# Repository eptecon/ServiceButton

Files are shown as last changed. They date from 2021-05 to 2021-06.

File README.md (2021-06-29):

ServiceButton: Connected Button for Notifications and Alarms
======

WiFi connected button that sends push notification data to an IoT platform. The notifications can be configured depending on use case.
Possible business cases are presented [here](/Docs).

### Hardware

ESP32 Microcontroller, simple push button, rechargeable battery.

### Firmware

The deevice connects with a server over WLAN. When button pressed, a notification message is composed from previously configured
data. The notification message is then sent in JSON format via TLS-secured MQTT protocol to the cloud service ([GlueLogics](https://github.com/eptecon/gluelogics)).

---

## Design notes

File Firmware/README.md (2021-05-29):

# GlueLogics Service Button

See the README.md file in the upper level directory for more information about this code.

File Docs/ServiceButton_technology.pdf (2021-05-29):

## Button – Use Case

Customer | Service Company

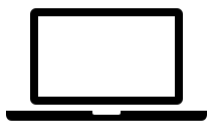
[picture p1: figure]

### Button on customer‘s side

### Service/Order Request in Service App

### Notifications/E-Mails to persons in charge and feedback to customer

Service App | E-Mail | Messenger

Button pressed by
customer

Action taken by
Service Company

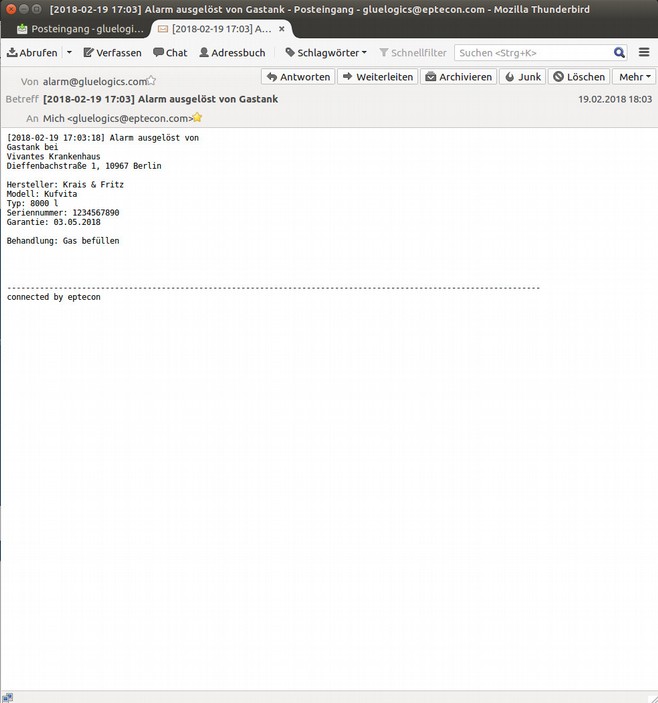
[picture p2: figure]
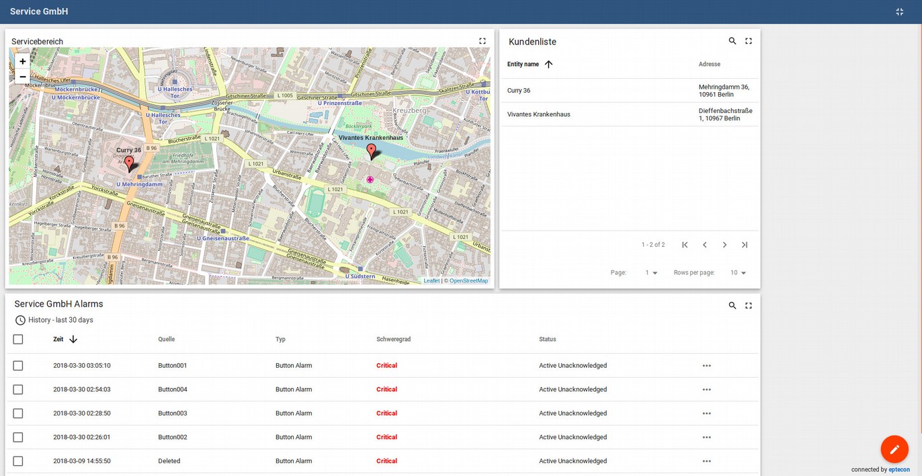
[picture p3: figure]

## Button – Business Process

### Button pressed by customer

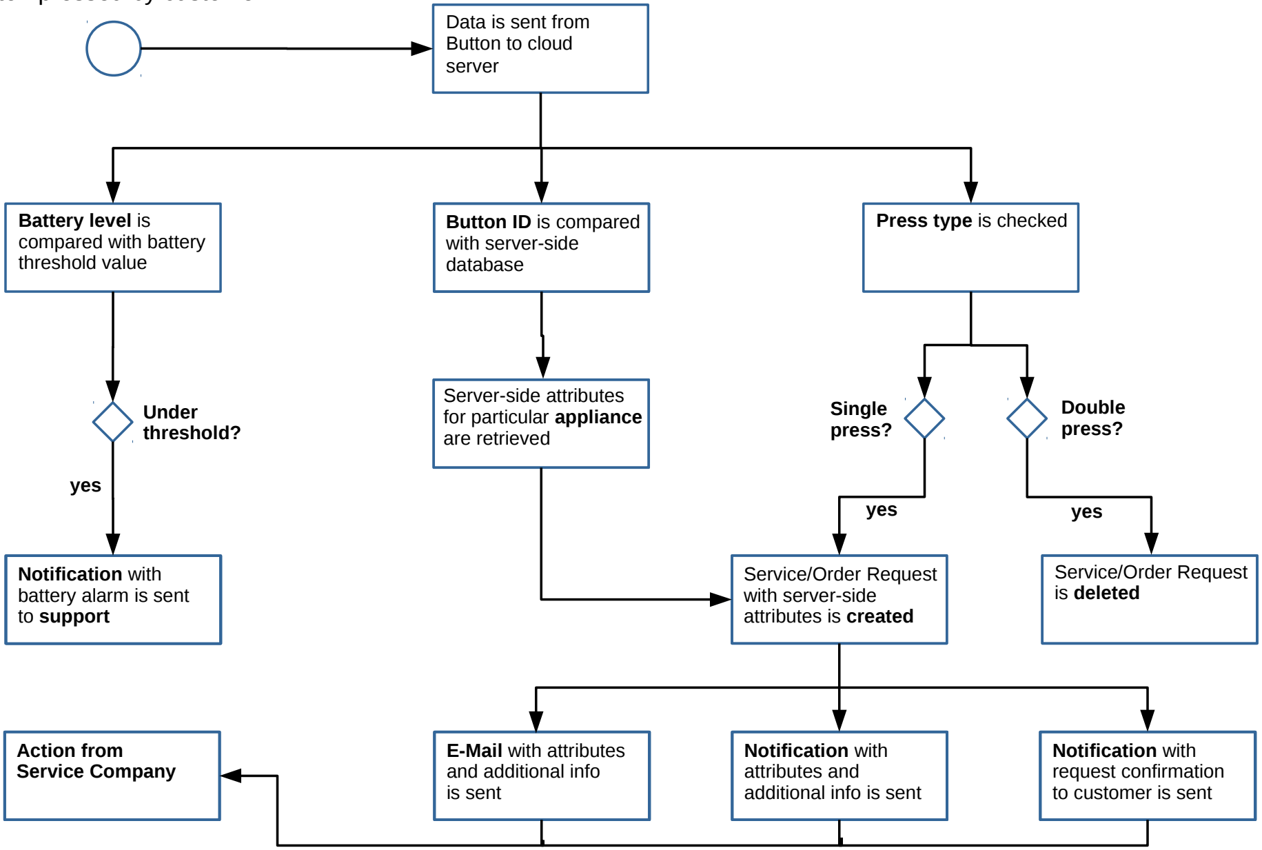
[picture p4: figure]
Data is sent from Button to cloud server; Button ID is compared with server-side database; Battery level is compared with battery threshold value; Press type is checked; Double press?; Single press?; Under threshold?; Service/Order Request with server-side attributes is created; Service/Order Request is deleted; Server-side attributes for particular appliance are retrieved; E-Mail with attributes and additional info is sent; Notification with request confirmation to customer is sent; Notification with attributes and additional info is sent; Notification with battery alarm is sent to support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

## Service/Order Request – Example Service App

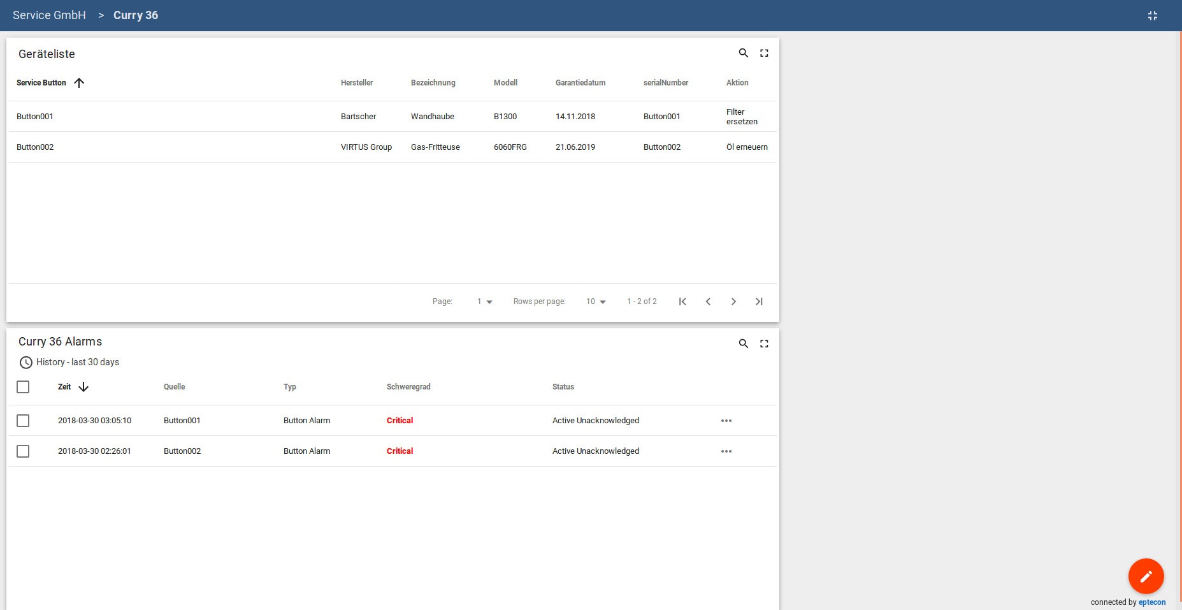
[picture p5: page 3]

## Service/Order Request – Example E-Mail

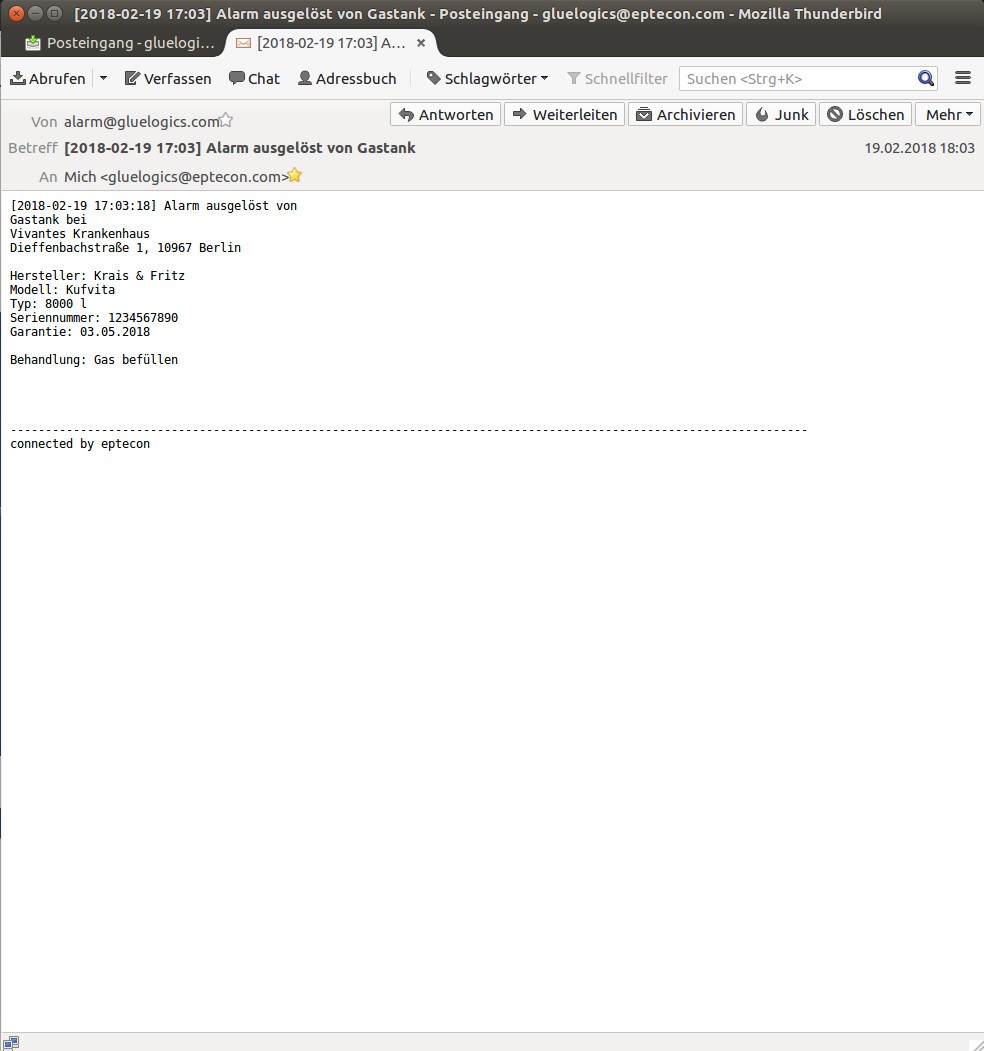
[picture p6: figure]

## Service/Order Request – Example Messenger

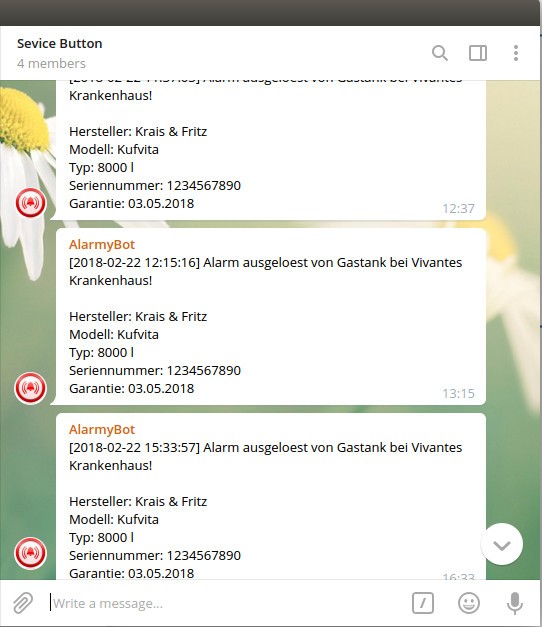
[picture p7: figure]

## Button – Installation/Customization Workflow

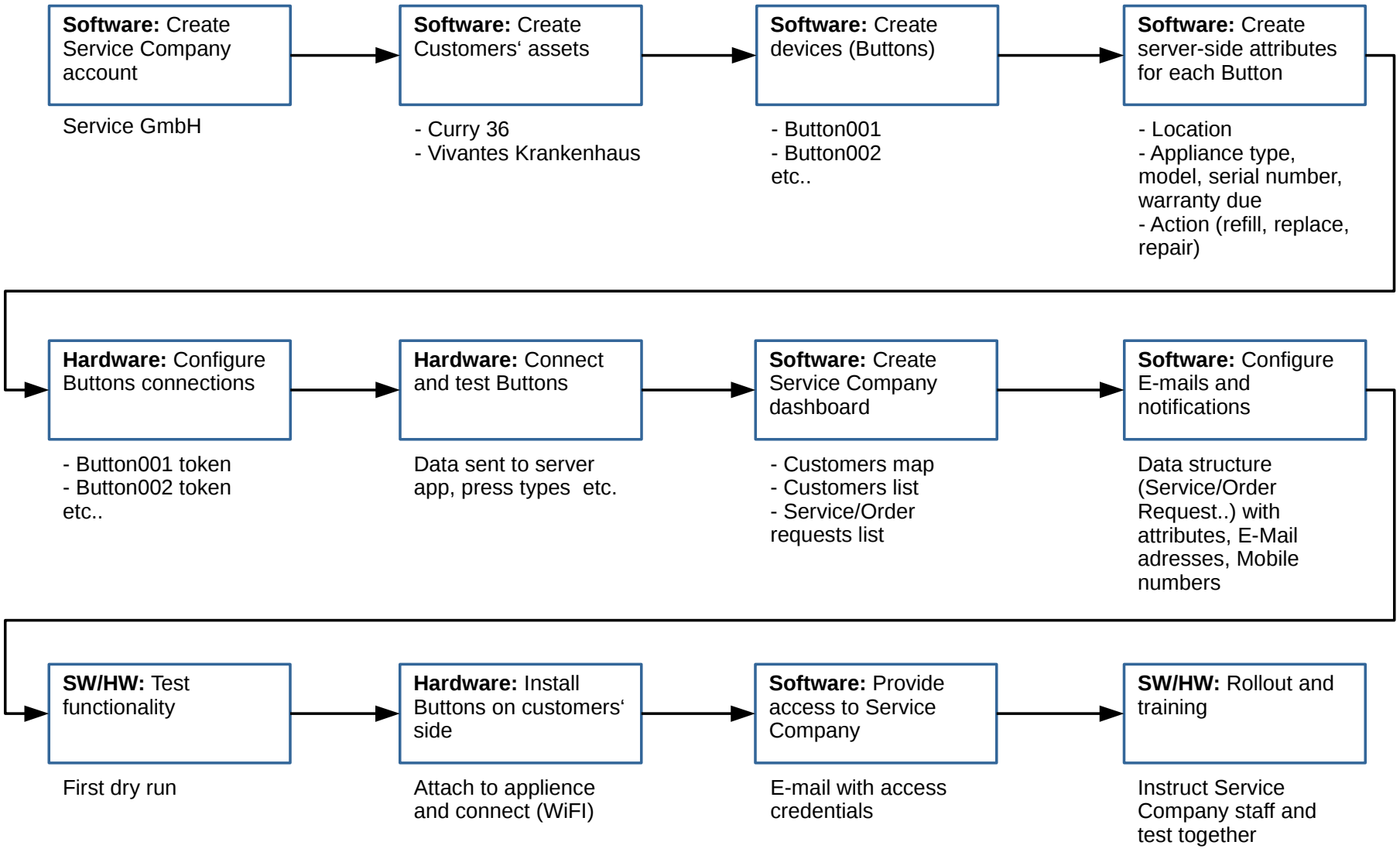
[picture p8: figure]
Software: Create Service Company account; Software: Create Customers‘ assets; Software: Create devices (Buttons); Software: Create server-side attributes for each Button; Hardware: Configure Buttons connections; Hardware: Connect and test Buttons; Software: Create Service Company dashboard; Software: Configure E-mails and notifications; SW/HW: Test functionality; Hardware: Install Buttons on customers‘ side; Software: Provide access to Service Company; SW/HW: Rollout and training; Service GmbH; - Curry 36; - Vivantes Krankenhaus; - Button001 - Button002 etc..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

## Button – Technology

Hardware | Cloud Software | Client Interface

### 1) AWS IoT Buttons: - ready to use - easy configuration - 20$ hardware - WiFi only - AWS IoT account - ca. 0.2 $ p. Button p. month

### 2) Own Buttons: - Hardware design required (specs!) - WiFi ready / GSM, LoRa possible - 1$ p. Button p. month for GSM

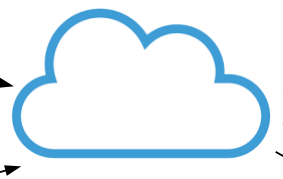
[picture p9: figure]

### Own cloud server: - runs Software (backend/frontend) - runs Database - ca. 20$ p. Month (all customers) - for AWS IoT Buttons additionaly AWS IoT service required

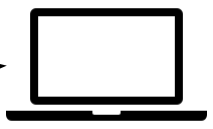
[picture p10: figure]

### Service App: - dashboards (overviews) - tickets system (different levels) - historical data E-Mail: - mail notifications on service/order Request (all necessary info) Messenger/SMS: - mobile notifications on service/ Order requests

## Button – Own Hardware

## Data:

- Button ID,
- Battery level,

### - Press type

## Connectivity:

### - WiFi (ready) - GSM (todo) - LoRa (todo?)

## Battery:

### - disposable? - rechargeable?

## Certifications

- CE

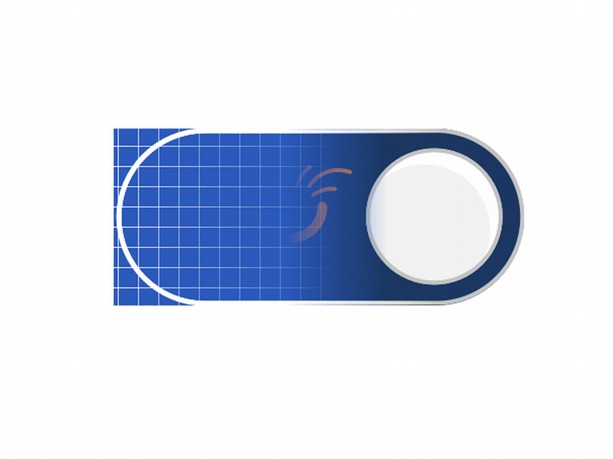
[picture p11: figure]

- BSI/CC, others?? | Case

### - Design - Drawings

Manufacturing | - Material

### - BOM - EMS (full service) - Tooling

## Button – Own Software: GlueLogics

### Internal (run on same server): - SQL Database - Soft-Gateway - Message Broker - Data analytics

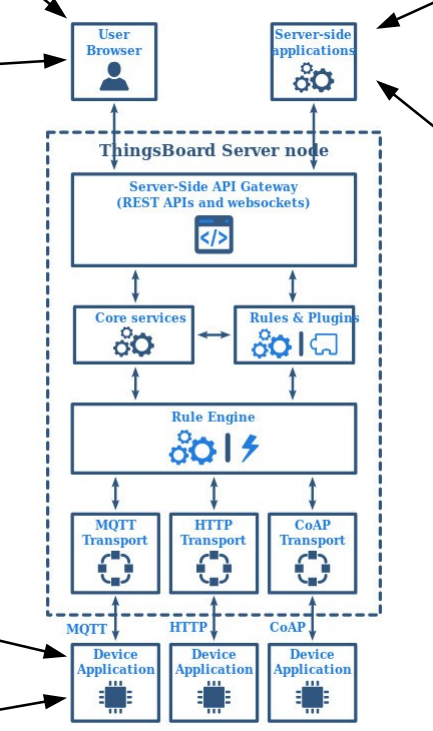
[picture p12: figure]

### External: - E-Mail Service - Telegram Bot - Message Broker - SMS Service - Others

### GlueLogics (www.gluelogics.com):

### - based on open source IoT platform „ThingsBoard“ - Multi-tenant - Cloud or on-premise deployable - APIs for external services - Persistence layer for data (integrated or external DB) - Internal data pre-prcessing - Customizable frontend (dashboards/maps) - Java, JavaScript, HTML, CSS

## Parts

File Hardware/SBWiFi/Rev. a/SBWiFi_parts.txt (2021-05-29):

Stückliste exportiert aus /home/erwin/Projekte/eagle/ServiceButton/SBWiFi/Rev. a/SBWiFi.sch am 06.07.18 11:51

Part Value                Device               Package                Description                                                                                       MF      MPN       OC_FARNELL OC_NEWARK PROD_ID    SF_SKU   
BT1                       BATTERY-AA           BATTERY-AA             Battery - Single Cell                                                                                                                    BATT-08316 PRT-07949
C1   10uF/25V(10%)        C-EUC0603            C0603                  CAPACITOR, European symbol                                                                                                                                   
C2   10uF/6.3V(10%)       C-EUC0603            C0603                  CAPACITOR, European symbol                                                                                                                                   
C3   1uF/10V(10%)         C-EUC0603            C0603                  CAPACITOR, European symbol                                                                                                                                   
C4   10uF/10V(10%)        C-EUC0603            C0603                  CAPACITOR, European symbol                                                                                                                                   
C5   100uF/6.3V(20%)      C-EUC0805            C0805                  CAPACITOR, European symbol                                                                                                                                   
C6   1uF/10V(10%)         C-EUC0603            C0603                  CAPACITOR, European symbol                                                                                                                                   
C7   1uF/10V(10%)         C-EUC0603            C0603                  CAPACITOR, European symbol                                                                                                                                   
C8   DNP                  C-EUC0603            C0603                  CAPACITOR, European symbol                                                                                                                                   
C9   100nF/25V(10%)       C-EUC0603            C0603                  CAPACITOR, European symbol                                                                                                                                   
C10  10uF/25V(10%)        C-EUC0603            C0603                  CAPACITOR, European symbol                                                                                                                                   
C11  10uF/25V(10%)        C-EUC0603            C0603                  CAPACITOR, European symbol                                                                                                                                   
C12  100nF/25V(10%)       C-EUC0603            C0603                  CAPACITOR, European symbol                                                                                                                                   
C13  100nF/25V(10%)       C-EUC0603            C0603                  CAPACITOR, European symbol                                                                                                                                   
D1   MBR120               MBR0520LT            SOD123                 SCHOTTKY BARRIER RECTIFIER                                                                                                                                   
J1                        USBMINIBLARGE        USB-MINIB_LARGER       USB Connectors                                                                                                                                               
J4   FTSH-105-01-XXX-DV-K FTSH-105-01-XXX-DV-K FTSH-105-01-XXX-DV-K   0.05"x0.05" DOUBLE ROW SMT STRIP ASSEMBLY.                                                                                                                   
LED1 ORANGE               LED0805_NOOUTLINE    CHIPLED_0805_NOOUTLINE LED                                                                                                                                                          
LED2 SML-LX0404           SML-LX0404           LED_RGB                                                                                                                                                                             
Q1   DMP2045U             MOSFET-P             SOT23-R                P-Channel Mosfet                                                                                                                                             
Q2   mmbt2222             TRANSISTOR_NPN       SOT23-R                NPN Transistor                                                                                                                                               
Q3   mmbt2222             TRANSISTOR_NPN       SOT23-R                NPN Transistor                                                                                                                                               
Q4   DMN2058U             MOSFET-NREFLOW       SOT23-R                N-Channel Mosfet                                                                                                                                             
R1   100k(1%)             R-EU_R0603           R0603                  RESISTOR, European symbol                                                                                                                                    
R2   100k(1%)             R-EU_R0603           R0603                  RESISTOR, European symbol                                                                                                                                    
R3   DNP                  R-EU_R0603           R0603                  RESISTOR, European symbol                                                                                                                                    
R4   100k(1%)             R-EU_R0603           R0603                  RESISTOR, European symbol                                                                                                                                    
R5   100k(1%)             R-EU_R0603           R0603                  RESISTOR, European symbol                                                                                                                                    
R6   1k(1%)               R-EU_R0603           R0603                  RESISTOR, European symbol                                                                                                                                    
R7   DNP                  R-EU_R0603           R0603                  RESISTOR, European symbol                                                                                                                                    
R8   750(1%)              R-EU_R0603           R0603                  RESISTOR, European symbol                                                                                                                                    
R9   270(1%)              R-EU_R0603           R0603                  RESISTOR, European symbol                                                                                                                                    
R10  330(1%)              R-EU_R0603           R0603                  RESISTOR, European symbol                                                                                                                                    
R11  0(1%)                R-EU_R0603           R0603                  RESISTOR, European symbol                                                                                                                                    
R12  10k(1%)              R-EU_R0603           R0603                  RESISTOR, European symbol                                                                                                                                    
R13  0(1%)                R-EU_R0603           R0603                  RESISTOR, European symbol                                                                                                                                    
R14  DNP                  R-EU_R0603           R0603                  RESISTOR, European symbol                                                                                                                                    
R15  10k(1%)              R-EU_R0603           R0603                  RESISTOR, European symbol                                                                                                                                    
R16  10k(1%)              R-EU_R0603           R0603                  RESISTOR, European symbol                                                                                                                                    
R17  0(1%)                R-EU_R0603           R0603                  RESISTOR, European symbol                                                                                                                                    
R18  0(1%)                R-EU_R0603           R0603                  RESISTOR, European symbol                                                                                                                                    
R19  DNP                  R-EU_R0603           R0603                  RESISTOR, European symbol                                                                                                                                    
R20  DNP                  R-EU_R0603           R0603                  RESISTOR, European symbol                                                                                                                                    
R21  470(1%)              R-EU_R0603           R0603                  RESISTOR, European symbol                                                                                                                                    
R22  0(1%)                R-EU_R0603           R0603                  RESISTOR, European symbol                                                                                                                                    
R23  0(1%)                R-EU_R0603           R0603                  RESISTOR, European symbol                                                                                                                                    
SW1  BUTTON               TACTILE-SWITCH-7914G 7914G                  Tactile Switch 4 Pins, SPST NO                                                                                                                               
SW2                       SKTDLDE010-T-SWITCH  T-SWITCH-ALPS-2                                                                                                                                                                     
SW3                       SKTDLDE010-T-SWITCH  T-SWITCH-ALPS-2                                                                                                                                                                     
U1   AP2112-3.3           VREG_SOT23-5         SOT23-5                SOT23-5 Fixed Voltage Regulators                                                                                                                             
U2   MCP73831T-2ACI/OT    MCP73831             SOT23-5                MCP73831 Miniature Single-Cell, Fully Integrated Li-Ion, Li-Polymer Charge Management Controllers                                                            
U3   ESP-WROOM-03         ESP-WROOM-03         ESP-WROOM-03                                                                                                                                                                        
U4   CP2102               CP2102               MLP28                  Single-Chip USB to UART Bridge                                                                    FARNELL CP2102-GM 9282130    30K5635

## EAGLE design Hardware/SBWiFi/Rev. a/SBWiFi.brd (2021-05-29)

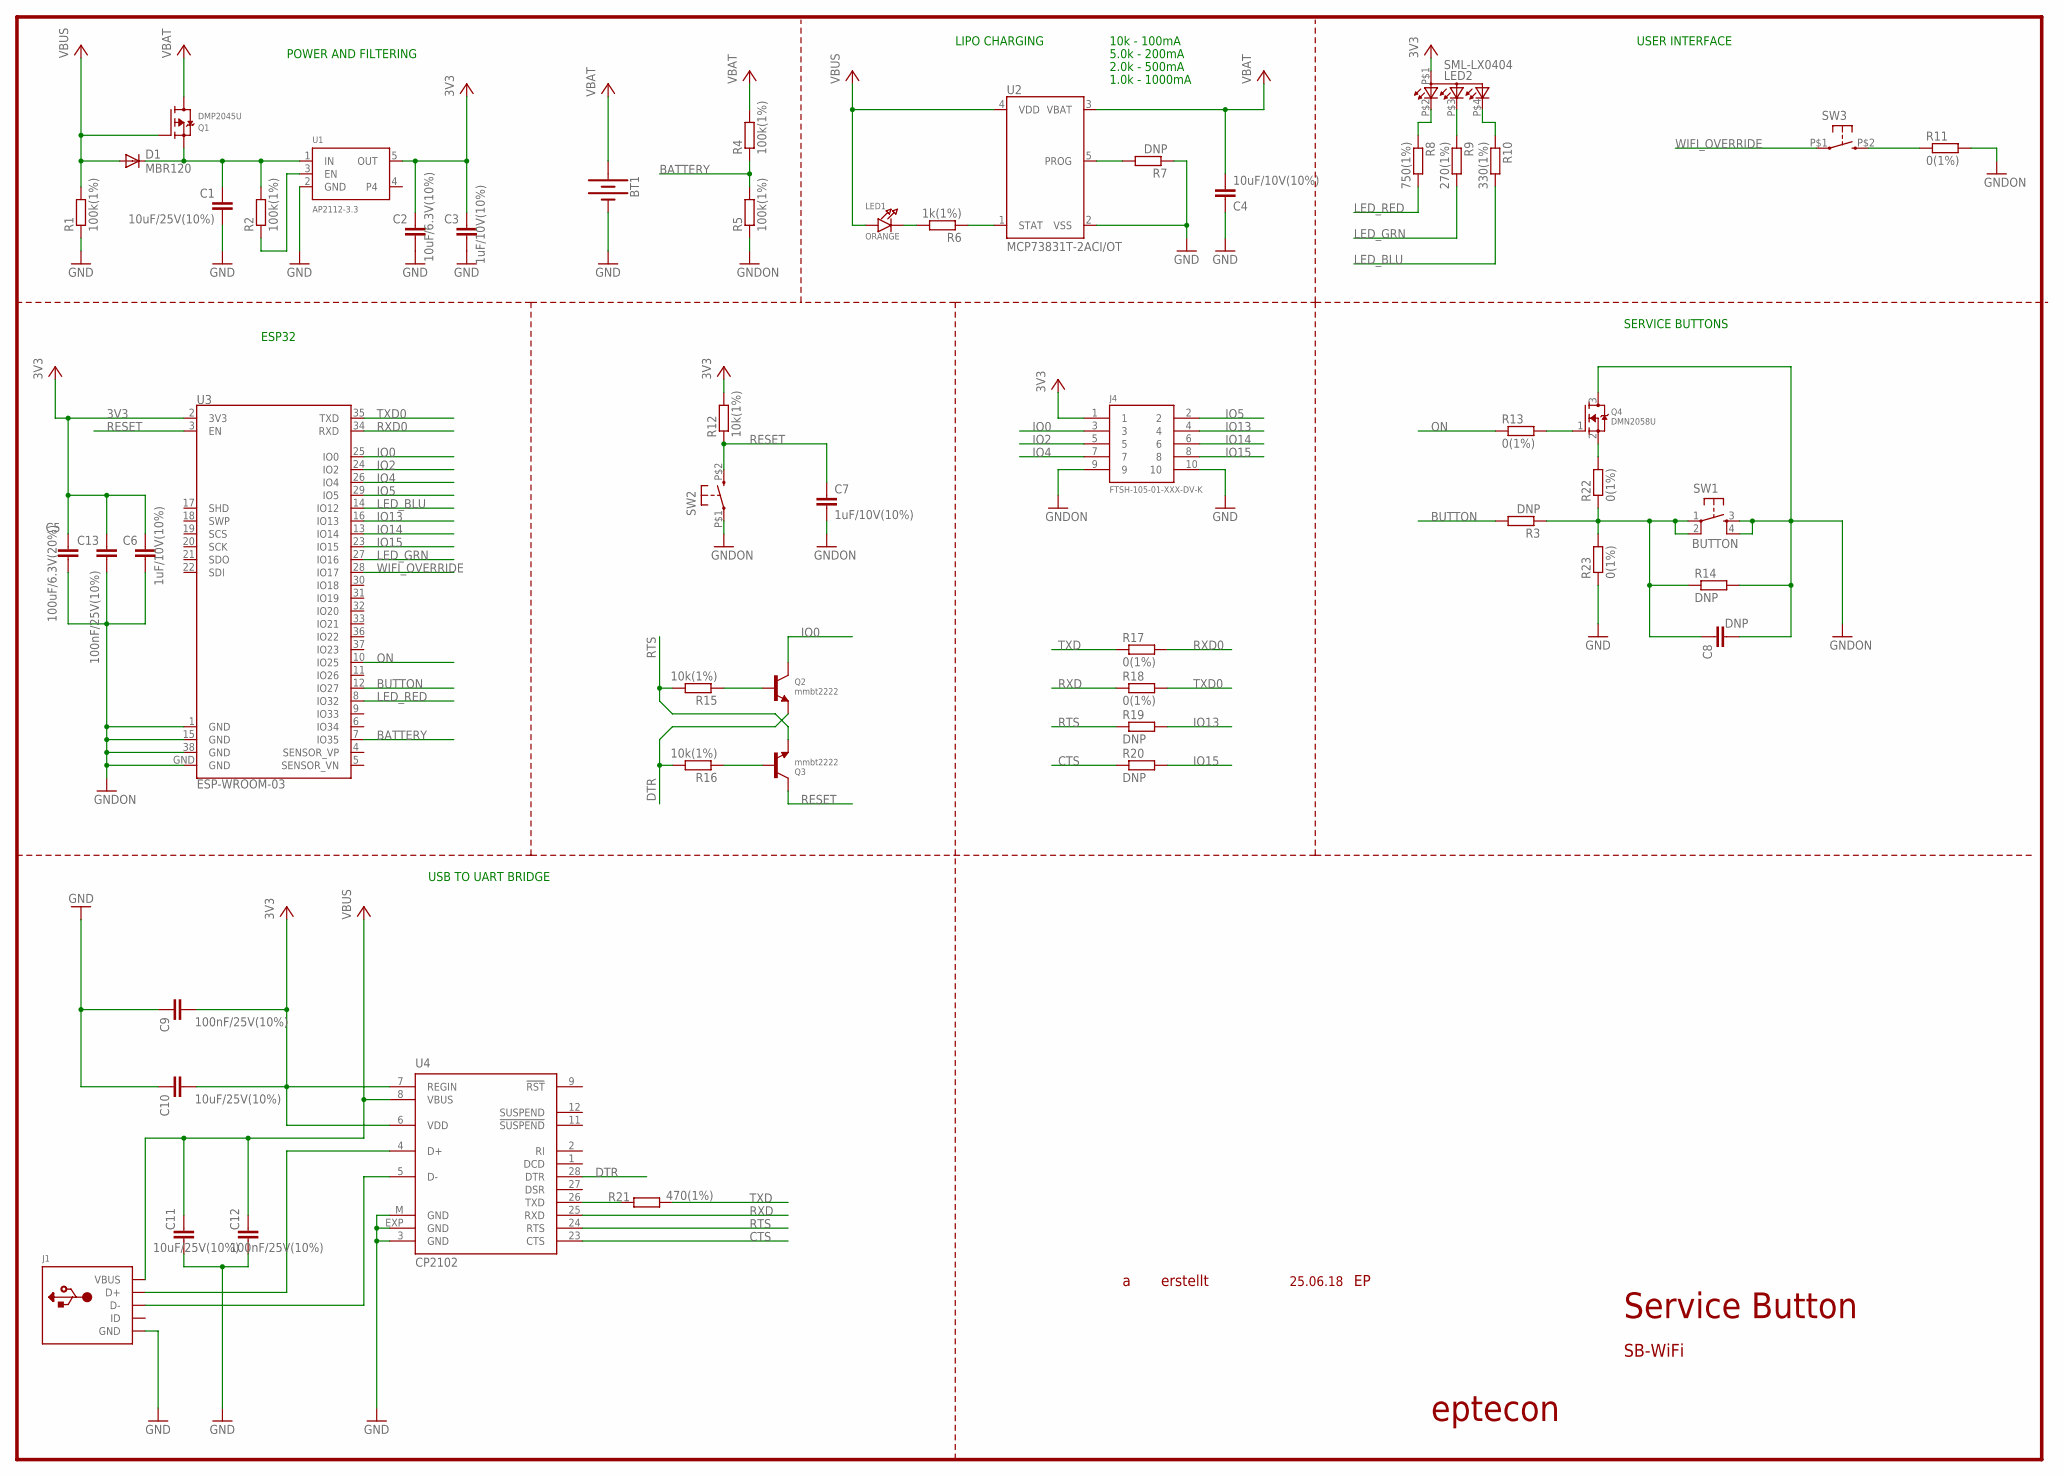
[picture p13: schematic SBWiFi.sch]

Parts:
BT1: BATTERY-AA
C1, C10, C11: 10uF/25V(10%); C0603
C2: 10uF/6.3V(10%); C0603
C3, C6, C7: 1uF/10V(10%); C0603
C4: 10uF/10V(10%); C0603
C5: 100uF/6.3V(20%); C0805
C8: DNP; C0603
C9, C12, C13: 100nF/25V(10%); C0603
D1: MBR120; SOD123
J1: USBMINIBLARGE; USB-MINIB_LARGER
J4: FTSH-105-01-XXX-DV-K
LED1: ORANGE; CHIPLED_0805_NOOUTLINE
LED2: SML-LX0404; LED_RGB
Q1: DMP2045U; SOT23-R
Q2, Q3: mmbt2222; SOT23-R
Q4: DMN2058U; SOT23-R
R1, R2, R4, R5: 100k(1%); R0603
R3, R7, R14, R19, R20: DNP; R0603
R6: 1k(1%); R0603
R8: 750(1%); R0603
R9: 270(1%); R0603
R10: 330(1%); R0603
R11, R13, R17, R18, R22, R23: 0(1%); R0603
R12, R15, R16: 10k(1%); R0603
R21: 470(1%); R0603
SW1: BUTTON; 7914G
SW2, SW3: SKTDLDE010-T-SWITCH; T-SWITCH-ALPS-2
U1: AP2112-3.3; SOT23-5
U2: MCP73831T-2ACI/OT; SOT23-5
U3: ESP-WROOM-03
U4: CP2102; MLP28

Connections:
3V3: C2.1, C3.1, C5.1, C6.1, C9.2, C10.2, C13.1, J4.1, LED2.P$1 (A2), R12.2, U1.5 (OUT), U3.2 (3V3), U4.6 (VDD), U4.7 (REGIN)
BATTERY: R4.1, R5.2, U3.7 (IO35)
BUTTON: R3.2, U3.12 (IO27)
CTS: R20.1, U4.23 (CTS)
DTR: Q2.2 (E), R16.2, U4.28 (DTR)
GND: BT1.GND@1 (-), C1.2, C2.2, C3.2, C4.1, C9.1, C10.1, C11.1, C12.1, J1.GND, J4.9, J4.10, R1.1, R5.1, R7.1, R11.2, R23.1, U1.2 (GND), U2.2 (VSS), U4.3 (GND), U4.EXP (GND), U4.M (GND)
GNDON: C5.2, C6.2, C7.2, C8.2, C13.2, Q4.3 (D), R14.2, SW1.3, SW1.4, SW2.P$1 (1), U3.1 (GND), U3.15 (GND), U3.38 (GND), U3.GND
IO0: J4.3, Q2.3 (C), U3.25 (IO0)
IO2: J4.5, U3.24 (IO2)
IO4: J4.7, U3.26 (IO4)
IO5: J4.2, U3.29 (IO5)
IO13: J4.4, R19.2, U3.16 (IO13)
IO14: J4.6, U3.13 (IO14)
IO15: J4.8, R20.2, U3.23 (IO15)
LED_BLU: R10.2, U3.14 (IO12)
LED_GRN: R9.2, U3.27 (IO16)
LED_RED: R8.2, U3.8 (IO32)
unnamed: LED2.P$2 (CRED), R8.1
unnamed: LED2.P$3 (CBLUE), R9.1
unnamed: LED2.P$4 (CGREEN), R10.1
unnamed: C8.1, R3.1, R14.1, R22.1, R23.2, SW1.1, SW1.2
unnamed: Q4.2 (S), R22.2
unnamed: Q4.1 (G), R13.2
unnamed: R2.1, U1.3 (EN)
unnamed: C1.1, D1.C, Q1.2 (S), R2.2, U1.1 (IN)
unnamed: Q3.1 (B), R16.1
unnamed: R21.1, U4.26 (TXD)
unnamed: Q2.1 (B), R15.1
unnamed: J1.D+, U4.4 (D+)
unnamed: J1.D-, U4.5 (D-)
unnamed: R11.1, SW3.P$2 (3)
unnamed: R6.1, U2.1 (STAT)
unnamed: LED1.C, R6.2
unnamed: R7.2, U2.5 (PROG)
ON: R13.1, U3.10 (IO25)
RESET: C7.1, Q3.3 (C), R12.1, SW2.P$2 (3), U3.3 (EN)
RTS: Q3.2 (E), R15.2, R19.1, U4.24 (RTS)
RXD: R18.1, U4.25 (RXD)
RXD0: R17.2, U3.34 (RXD)
TXD: R17.1, R21.2
TXD0: R18.2, U3.35 (TXD)
VBAT: BT1.PWR@1 (+), C4.2, Q1.3 (D), R4.2, U2.3 (VBAT)
VBUS: C11.2, C12.2, D1.A, J1.VBUS, LED1.A, Q1.1 (G), R1.2, U2.4 (VDD), U4.8 (VBUS)
WIFI_OVERRIDE: SW3.P$1 (1), U3.28 (IO17)

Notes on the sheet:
Service Button
SB-WiFi
eptecon
erstellt
25.06.18
ESP32
POWER AND FILTERING
USB TO UART BRIDGE
LIPO CHARGING
10k - 100mA
5.0k - 200mA
2.0k - 500mA
1.0k - 1000mA
USER INTERFACE
SERVICE BUTTONS

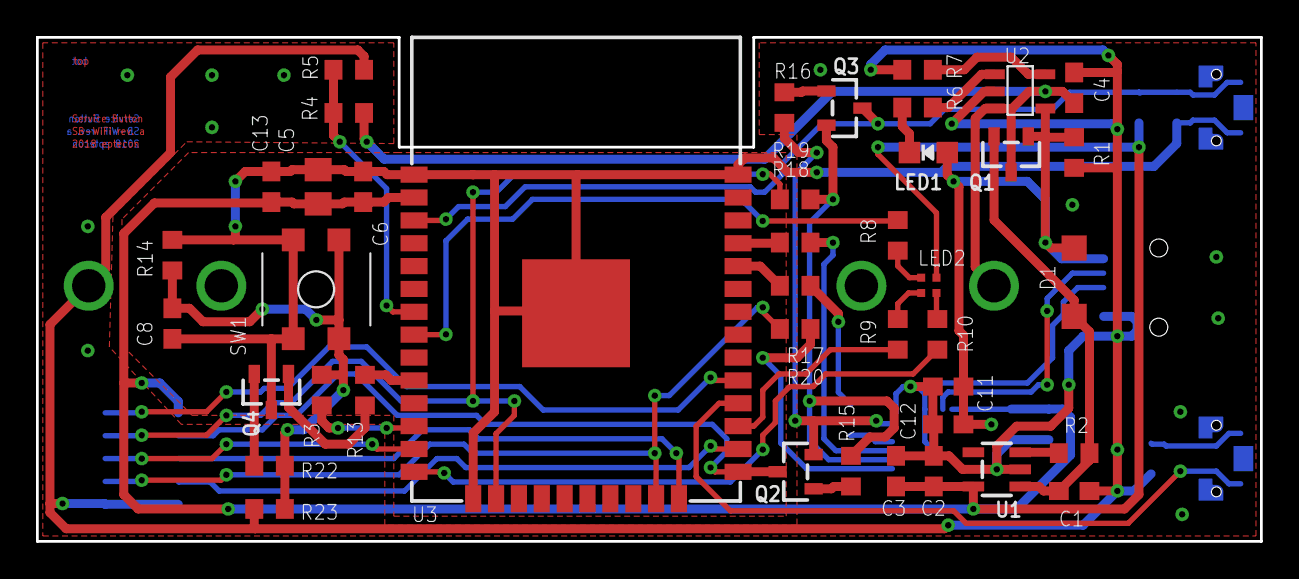
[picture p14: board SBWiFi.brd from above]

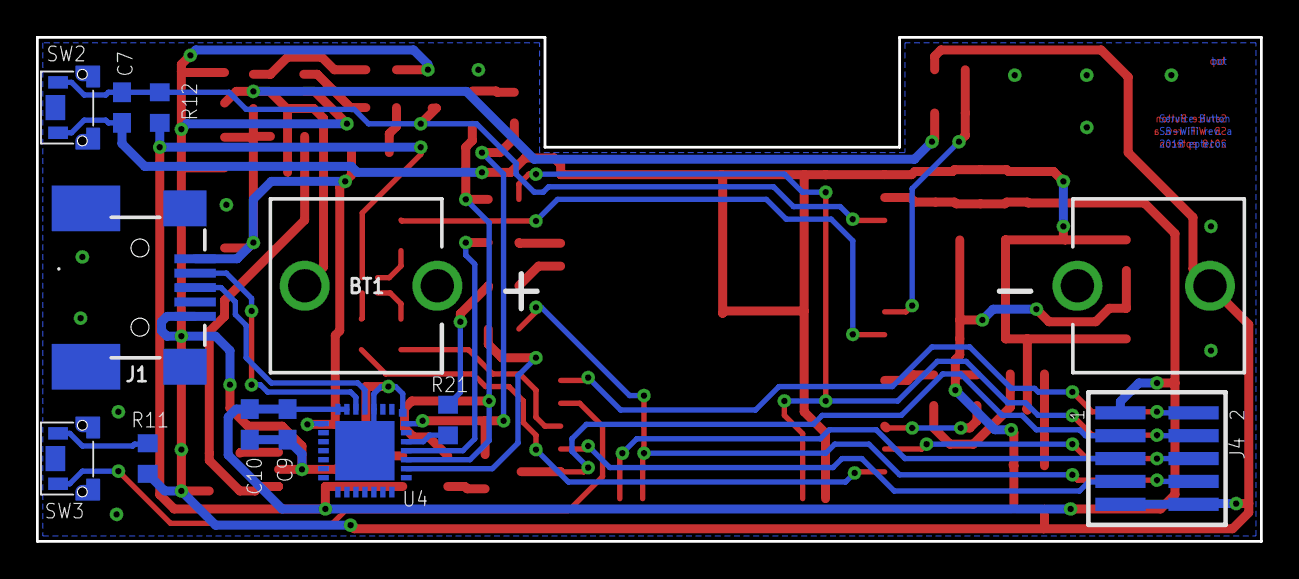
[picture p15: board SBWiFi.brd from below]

Board: 2 copper layers, 68.0 x 28.0 mm, 53 parts (12 on the bottom side), 44 nets.

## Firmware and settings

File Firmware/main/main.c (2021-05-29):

/* Main -  GlueLogics System Core
 *
 *
 *
 */
#include <stdlib.h>

#include "freertos/FreeRTOS.h"
#include "freertos/task.h"

#include "esp_err.h"
#include "esp_log.h"

#include "app_gl_ctrl.h"
#include "app_gl_startup.h"

#include "led_blinker.h"

#include "fw_version.h"


void app_main() {

	ESP_LOGI("FW", "running fw version %s", FW_VERSION);

	xTaskCreatePinnedToCore(&led_blinker_task, "led_task",  1 * 1024, NULL, 6, NULL, 1);

	app_gl_startup();
	
	xTaskCreatePinnedToCore(&app_gl_ctrl, "gl_ctrl", 12 * 1024, NULL, 5, NULL, 0);

}

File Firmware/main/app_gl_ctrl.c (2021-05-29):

/* Controller -  GlueLogics System Business Logic
 *
 *
 *
 */
#include <string.h>

#include "freertos/FreeRTOS.h"
#include "freertos/task.h"
#include "freertos/event_groups.h"
#include "esp_event_loop.h"
#include "esp_log.h"
#include "esp_system.h"

#include "mqtt_publish.h"
#include "mqtt_subscribe.h"

#include "led_blinker.h"

#include "json_util.h"


#define LONG_PRESS_PERIOD_MS 100
#define BTN_SENSE_BIT BIT0
#define KEY_GPIO_NUM 27
#define KEY_ACTIVE 1
#define GLITCH_TIMEOUT_MS 500

#define SERIAL "Button001"

#define TOPIC1 "v1/devices/me/attributes"
#define TOPIC2 "v1/devices/me/telemetry"

static EventGroupHandle_t button_event_group;

static const char *TAG = "gl_ctrl";

static void IRAM_ATTR gpio_isr_handler_up(void* arg) {
	BaseType_t xHigherPriorityTaskWoken = pdFALSE;
	xEventGroupSetBitsFromISR(button_event_group, BTN_SENSE_BIT, &xHigherPriorityTaskWoken);
	portYIELD_FROM_ISR();
}

void init_gpio(void) {
	/*
	 * Setup button GPIO
	 */
	gpio_config_t io_conf = {
		.pin_bit_mask = 1 << KEY_GPIO_NUM,
		.mode = GPIO_MODE_INPUT,
		.pull_down_en = GPIO_PULLDOWN_ENABLE,
		.pull_up_en = GPIO_PULLUP_DISABLE,
		.intr_type = GPIO_INTR_POSEDGE,
	};
	gpio_config(&io_conf);
	printf("Button configured\n");
	
	gpio_intr_enable(KEY_GPIO_NUM);
	gpio_install_isr_service(0);
	gpio_isr_handler_add(KEY_GPIO_NUM, gpio_isr_handler_up, (void*) KEY_GPIO_NUM);
}

void app_gl_ctrl(void *arg) {
	
	EventBits_t bits;
	button_event_group = xEventGroupCreate();
	
	init_gpio();
	
	char *msg1, *msg2;
	char batt_value[32], click_type[32];

	//sprintf(batt_value1, "%d",(uint8_t)(esp_random()&0xFF));
		
	/*Create JSON Object*/
	msg1 = json_create(SERIAL);
	printf("%s\n",msg1);
	
	mqtt_pub(TOPIC1, msg1);
	

    while(1) {
       
		led_blinker_set_mode(BLINK_MODE_CONNECTED);
		vTaskDelay(1000 / portTICK_RATE_MS);
		ESP_LOGI(TAG, "Wait for button pressed...");
		
		if (gpio_get_level(KEY_GPIO_NUM) != KEY_ACTIVE) {
			vTaskDelay(GLITCH_TIMEOUT_MS / portTICK_RATE_MS);

			if (gpio_get_level(KEY_GPIO_NUM) != KEY_ACTIVE) {
				
				led_blinker_set_mode(BLINK_MODE_STARTED);

				bits = xEventGroupWaitBits(button_event_group, 
					BTN_SENSE_BIT, 
					pdTRUE, 
					pdTRUE, 
					LONG_PRESS_PERIOD_MS / portTICK_RATE_MS);
				
				if (bits != 0) {
					
					sprintf(batt_value, "%d",(uint8_t)(esp_random()&0xFF));
					sprintf(click_type,"SINGLE");
		
					/*Create JSON Object*/
					msg2 = json_update(batt_value, click_type);
					printf("%s\n",msg2);
					
					mqtt_pub(TOPIC2, msg2);
					//mqtt_sub();
					
					vTaskDelay(1000 / portTICK_RATE_MS);
					
					//led_blinker_set_mode(BLINK_MODE_CONNECTED);
					//ESP_LOGI(TAG, "Wait for button pressed...");	
					
					//xEventGroupClearBits(button_event_group, BTN_SENSE_BIT);
				}
			
			}
		}
	}	
}
 
 

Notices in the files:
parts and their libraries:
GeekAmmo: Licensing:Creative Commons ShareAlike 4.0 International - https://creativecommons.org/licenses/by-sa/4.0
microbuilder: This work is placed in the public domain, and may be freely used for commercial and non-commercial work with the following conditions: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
